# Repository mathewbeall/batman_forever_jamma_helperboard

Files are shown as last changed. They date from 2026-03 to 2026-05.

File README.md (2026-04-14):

# Batman Forever JAMMA Adapter

A JAMMA edge adapter board for the **Sega ST-V** arcade platform that enables the [Mitsurugi-w Batman Forever sound board repro](https://www.arcade-projects.com/threads/wait-list-batman-forever-sound-pcb-repro.27304/) to work in generic JAMMA cabinets.

This is a recreation and improvement of Derick2k's original design from the arcade-projects.com forum (thread post #191), which was abandoned ~2 years ago and never released.

> **Current production version: V1.2** — Fully tested and validated.
> **V1.3** — Design complete, not yet ordered or tested. See [V1.3 changes](#v13-changes-untested) below.

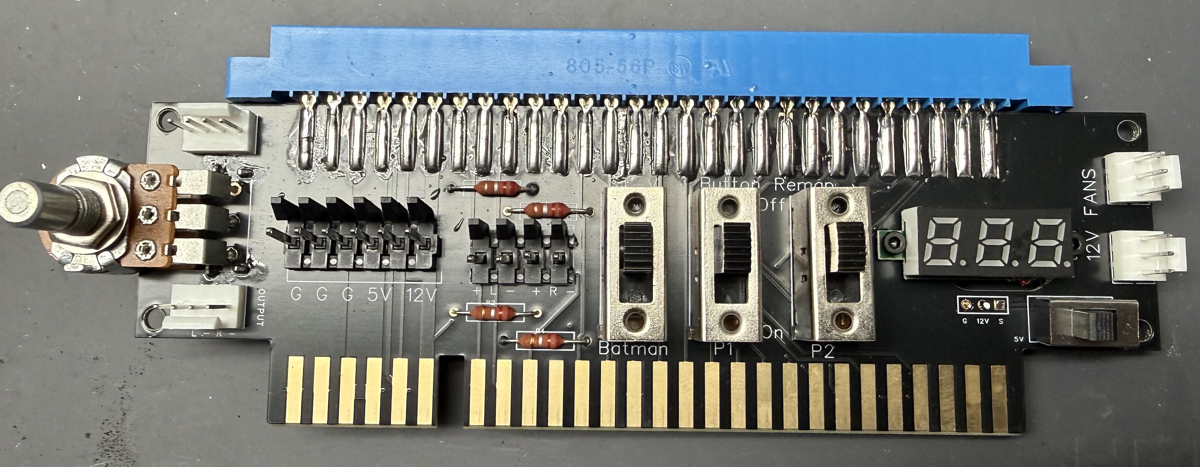
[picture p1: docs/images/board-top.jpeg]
Board top side

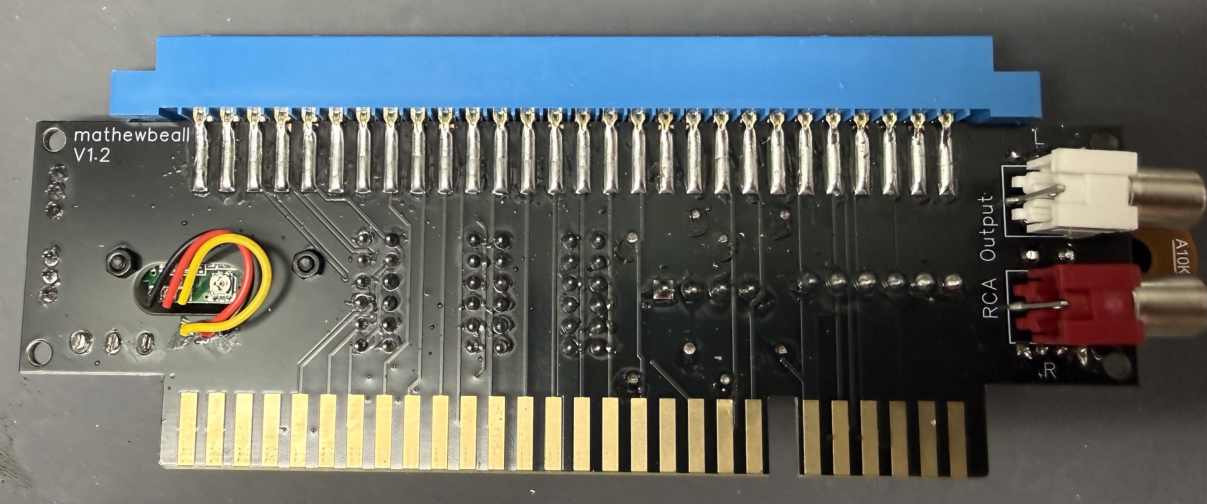
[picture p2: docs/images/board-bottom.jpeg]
Board bottom side

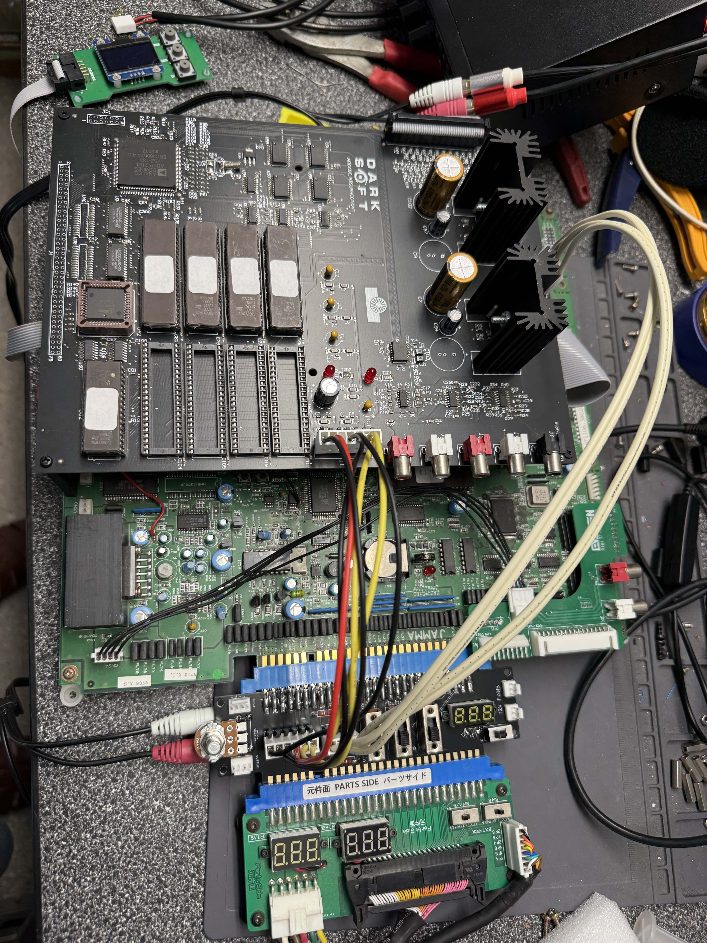
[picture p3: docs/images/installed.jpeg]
Installed with ST-V and sound board


---

## Features

- **Full JAMMA passthrough** — Video, controls, coins, test, service all pass through untouched
- **Power distribution** — Taps JAMMA 5V/12V/GND to power the sound board, fan headers, and voltmeter
- **Audio switching** — Single 4PDT slide switch selects ST-V native audio or Batman sound board output
- **Stereo-to-mono downmix** — Sound board's amplified stereo (BTL) output is summed to mono for the single JAMMA cabinet speaker
- **Button remapping** — Two 4PDT slide switches shift P1/P2 button mapping (Batman uses buttons 2/3/4 instead of 1/2/3)
- **Line-level audio** — Independent path with dual-gang volume pot, RCA jacks, and pin headers for external amplifiers
- **Voltage monitoring** — Slide switch selects 5V or 12V rail for a 0.28" voltmeter display module
- **Fan headers** — Two 3-pin fan connectors with 12V power
- **All through-hole** — Zero SMD components. Four resistors (audio ballast) are the only passives. Hand-solder friendly.

## Board Specifications

| Parameter | Value |
|---|---|
| Dimensions | 157mm x 50mm |
| Layers | 4 (Top, Inner1 GND, Inner2 Power, Bottom) |
| Copper Weight | 2oz all layers |
| PCB Color | Black solder mask, white silkscreen |
| Surface Finish | ENIG with gold fingers |
| Gold Finger Bevel | 45 degrees |
| Thickness | 1.6mm |
| Design Tool | EasyEDA Pro (JLCEDA Pro) |

---

## V1.2 — Production Version (Tested)

V1.2 is the current production version. Boards have been ordered, received, and fully validated.

**Quick Start (V1.2):**

1. **Order PCBs** — See the [Ordering Guide](docs/ordering-guide.md) for JLCPCB settings
2. **Order components** — See the [Bill of Materials](v1.2/bom.md) (~$32 per board in components)
3. **Build cables** — See the [Cable Build Guide](docs/cable-builds.md) for power and speaker cables
4. **Assemble** — See the [Assembly Guide](v1.2/assembly-guide.md) for soldering and setup instructions
5. **Install** — Set switches, plug into your cabinet, and play

**V1.2 Files:**

| File | Description |
|---|---|
| [v1.2/Batman_Forever_JAMMA_Adapter_V1.2.eprj](v1.2/Batman_Forever_JAMMA_Adapter_V1.2.eprj) | EasyEDA Pro project file |
| [v1.2/Gerber_PCB2_2026-03-20.zip](v1.2/Gerber_PCB2_2026-03-20.zip) | Production Gerbers for JLCPCB (tested) |
| [v1.2/assembly-guide.md](v1.2/assembly-guide.md) | Assembly guide |
| [v1.2/bom.md](v1.2/bom.md) | Bill of materials with full pricing |

**V1.2 switch note:** SW1/SW2/SW4 use the SS42H11-G9 4PDT slide switch (AliExpress). Before soldering, snip all 4 mounting lugs flush on each switch.

---

## V1.3 Changes (Untested)

> **V1.3 has not been ordered or tested.** The design is complete but unvalidated. Use V1.2 for production builds.

V1.3 replaces the three 4PDT slide switches (SW1/SW2/SW4) with the **Alps Alpine SSSU042100**, available from Mouser Electronics. The motivation is reliable domestic sourcing — the SS42H11-G9 used in V1.2 is only available from AliExpress with unpredictable lead times.

**What changed:**

| | V1.2 | V1.3 |
|--|---|---|
| Switch part | SS42H11-G9 (AliExpress) | SSSU042100 (Mouser 688-SSSU042100) |
| Row spacing | 4.0mm | 2.5mm |
| Pad drill | 1.1mm | 0.7mm |
| Mounting | 4 metal lugs to snip before soldering | Metal snap-in clips seat into 2 NPTH slots (1.5mm × 1.5mm) in the PCB — no prep required |
| Schematic | unchanged | unchanged |
| Electrical behavior | baseline | identical |

The SSSU042100 is electrically pin-compatible with the SS42H11-G9 — same 4PDT function, same 12-pin layout, same 3mm pitch. No schematic changes. The only differences are physical: smaller pin diameter (0.7mm vs 1.1mm), tighter row spacing (2.5mm vs 4.0mm), and a snap-in mounting mechanism that eliminates the lug-snipping step required on V1.2.

**V1.3 Files:**

| File | Description |
|---|---|
| [v1.3/Batman_Forever_JAMMA_Adapter_V1.3.eprj](v1.3/Batman_Forever_JAMMA_Adapter_V1.3.eprj) | EasyEDA Pro project file |
| [v1.3/Gerber_PCB2_2026-04-13.zip](v1.3/Gerber_PCB2_2026-04-13.zip) | Gerbers for JLCPCB (not yet ordered) |
| [v1.3/assembly-guide.md](v1.3/assembly-guide.md) | Assembly guide |
| [v1.3/bom.md](v1.3/bom.md) | Bill of materials with full pricing |

---

## Shared Documentation

| Document | Description |
|---|---|
| [Cable Build Guide](docs/cable-builds.md) | Power cable and speaker cable pinouts, crimping, safety |
| [Ordering Guide](docs/ordering-guide.md) | JLCPCB order settings and Gerber export instructions |

---

## Repository Structure

```
v1.2/                                    V1.2 — tested production version
  Batman_Forever_JAMMA_Adapter_V1.2.eprj   EasyEDA Pro project file
  Gerber_PCB2_2026-03-20.zip               Production Gerbers for JLCPCB
  assembly-guide.md                        Assembly guide
  bom.md                                   Bill of materials

v1.3/                                    V1.3 — design complete, NOT TESTED
  Batman_Forever_JAMMA_Adapter_V1.3.eprj   EasyEDA Pro project file
  Gerber_PCB2_2026-04-13.zip               Gerbers for JLCPCB (not yet ordered)
  assembly-guide.md                        Assembly guide
  bom.md                                   Bill of materials

docs/                                    Shared documentation
  cable-builds.md                          Power and speaker cable builds
  ordering-guide.md                        JLCPCB order settings
  images/                                  Board photos

soundboard_mounting_kit.scad/.stl        3D-printable sound board mounting parts
```

---

## 3D-Printable Sound Board Mounting Kit

The sound board mounts above the ST-V motherboard on standoffs, but the mounting holes don't align perfectly. The file `soundboard_mounting_kit.stl` contains a set of 3D-printable parts to bridge the gap:

| Part | Description |
|---|---|
| **Shim A** | 6mm offset adapter (single axis), M3 countersunk |
| **Shim B** | 6mm + 10mm offset adapter (two axes), M3 countersunk |
| **Spacer C** | Plain 3mm M3 spacer for aligned holes |
| **L-Bracket** | 25mm horizontal / 53mm vertical standoff for mounting points with no existing standoff |

All parts are 3mm thick (except the L-bracket pillar). M3 hardware throughout. Print in PETG or PLA, no supports needed. The OpenSCAD source (`soundboard_mounting_kit.scad`) is included if you need to adjust offsets.

---

## Stereo-to-Mono Downmixing

The Batman Forever sound board outputs amplified stereo via a bridged (BTL) amplifier — four wires: L+, L-, R+, R-. JAMMA only has a single speaker output (Speaker+, Speaker-).

SW4 (4PDT slide switch) handles this with direct BTL parallel summing: in Batman mode, L+ and R+ are tied together on Speaker+, and L- and R- are tied together on Speaker-. The speaker sees the sum of both channels across its terminals.

**V1.1** connects the channels directly, which works in practice but is not ideal — gain mismatch between channels can cause one to fight the other. **V1.2** adds four 0.22 ohm 1W series resistors (R1–R4) on the speaker lines between J4 and SW4 as current-sharing ballast, following the same approach recommended in TI's amplifier application notes. The resistors are small enough relative to the 8 ohm speaker load (2.75%) that audio loss is negligible.

In ST-V mode, SW4 simply passes the native JAMMA audio straight through to the cabinet.

The line-level audio path (RV1, RCA jacks, pin headers) is completely independent and always active regardless of SW4 position.

---

## Switch Settings

### SW4 — Audio Source
| Position | Mode | Description |
|---|---|---|
| Up (toward JAMMA edge) | **ST-V** | Native JAMMA audio passthrough |
| Down (toward tab) | **Batman** | Sound board audio to cabinet speakers |

### SW1/SW2 — Button Remap (P1/P2)
| Position | Mode | Description |
|---|---|---|
| Up (toward JAMMA edge) | **Off** | Normal 1:1 button passthrough |
| Down (toward tab) | **On** | Batman remap (shifts buttons +1) |

### SW3 — Voltmeter Select
| Position | Mode |
|---|---|
| Left | Displays 5V rail |
| Right | Displays 12V rail |

---

## Credits

- **Derick2k** — Original adapter board concept and PCB design (abandoned, never released)
- **Mitsurugi-w** — Batman Forever sound board reproduction
- **twistedsymphony** — Sound board connector pinouts from the original manual
- **Matt (mathewbeall)** — PCB recreation, schematic, and layout in EasyEDA Pro
- **arcade-projects.com community** — Testing, feedback, and support

## Forum Thread

[Interest List — Helper Board for Mitsu's Repro Batman Forever Sound/Amp Board](https://www.arcade-projects.com/threads/interest-list-helper-board-for-mitsus-repro-batman-forever-sound-amp-board.36822/)

## License

This project is licensed under the [CERN Open Hardware Licence Version 2 — Strongly Reciprocal (CERN-OHL-S-2.0)](LICENSE).

You are free to use, modify, and distribute this design. If you distribute modified versions, they must also be shared under the same licence.

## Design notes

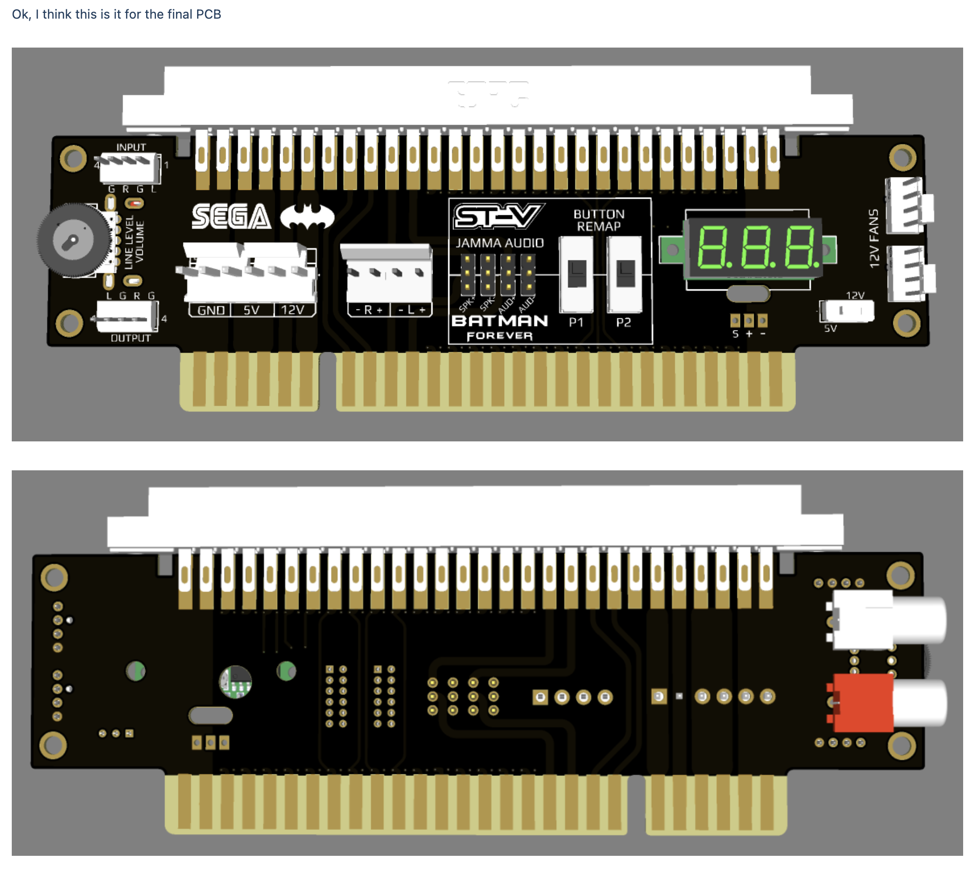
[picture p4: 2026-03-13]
final design.png

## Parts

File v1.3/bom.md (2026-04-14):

# Batman Forever JAMMA Adapter — Bill of Materials (V1.3)
**Last Updated: 2026-04-13**
**V1.3 change: SW1/SW2/SW4 switched from SS42H11-G9 (AliExpress) to Alps SSSU042100 (Mouser)**
**All prices verified against vendor listings**

---

## Per-Board Component Cost Summary

| Category | Subtotal |
|---|---|
| DigiKey — PCB-mount components | $4.95 |
| DigiKey — Cable parts | $6.15 |
| Mouser — Switches | $7.08 |
| Amazon — Voltmeter, IDE cable, SW3 | $4.90 |
| Adafruit — Pot | $2.75 |
| Memotronics — JAMMA connector | $2.69 |
| Wire (estimated per board) | $3.50 |
| **Components subtotal** | **$32.02** |
| Shipping estimate (10%) | $3.20 |
| **Total per board (components + shipping)** | **$35.22** |
| PCB cost (TBD — V1.3 not yet ordered) | TBD |
| **Grand total per assembled unit** | **TBD** |

---

## DigiKey — PCB-Mount Components

| Ref | Qty | Description | Mfr Part # | DigiKey Part # | Link | Price | Ext |
|-----|-----|---|---|---|---|---|-----|
| J3 | 1 | Molex KK 396 header, 6-pos, vertical, 3.96mm (power) | 0026481065 | WM50008-06-ND | [DigiKey](https://www.digikey.com/en/products/detail/molex/0026481065/26763) | $1.02 | $1.02 |
| J4 | 1 | Molex KK 396 header, 4-pos, vertical, 3.96mm (speaker) | 0026481045 | WM50008-04-ND | [DigiKey](https://www.digikey.com/en/products/detail/molex/0026481045/26759) | $0.79 | $0.79 |
| J7 | 1 | Kycon RCA jack, right-angle, 2-pin, RED (Left audio) | KLPX-0848A-2-R | 2092-KLPX-0848A-2-R-ND | [DigiKey](https://www.digikey.com/en/products/detail/kycon-inc/KLPX-0848A-2-R/9990119) | $0.83 | $0.83 |
| J8 | 1 | Kycon RCA jack, right-angle, 2-pin, WHITE (Right audio) | KLPX-0848A-2-W | 2092-KLPX-0848A-2-W-ND | [DigiKey](https://www.digikey.com/en/products/detail/kycon-inc/KLPX-0848A-2-W/9990120) | $0.83 | $0.83 |
| J9 | 1 | Molex KK 254, 4-pos, vertical, shrouded (line in) | 22-23-2041 | WM4202-ND | [DigiKey](https://www.digikey.com/en/products/detail/molex/0022232041/26671) | $0.26 | $0.26 |
| J10 | 1 | Molex KK 254, 4-pos, vertical, shrouded (line out) | 22-23-2041 | WM4202-ND | [DigiKey](https://www.digikey.com/en/products/detail/molex/0022232041/26671) | $0.26 | $0.26 |
| J14 | 1 | Molex KK 254, 3-pos, vertical, shrouded (fan) | 22-23-2031 | WM4201-ND | [DigiKey](https://www.digikey.com/en/products/detail/molex/0022232031/26669) | $0.22 | $0.22 |
| J15 | 1 | Molex KK 254, 3-pos, vertical, shrouded (fan) | 22-23-2031 | WM4201-ND | [DigiKey](https://www.digikey.com/en/products/detail/molex/0022232031/26669) | $0.22 | $0.22 |
| R1-R4 | 4 | 0.22 ohm 1W 5% axial resistor, metal film (audio ballast) | RR01JR22TB | A131610CT-ND | [DigiKey](https://www.digikey.com/en/products/detail/te-connectivity-passive-product/RR01JR22TB/2384744) | $0.13 | $0.52 |
| | | | | | | **Subtotal:** | **$4.95** |

**Note:** J3, J4, J9, J10, J14, J15 are dedicated Molex headers (not cut from breakaway strips). Voltmeter wires solder directly to pads — no header needed.

---

## DigiKey — Power Cable Parts (J3 → Sound Board J1)

| Qty | Description | Mfr Part # | DigiKey Part # | Link | Price | Ext |
|-----|---|---|---|---|---|-----|
| 1 | KK .156" 6-pin crimp housing (adapter J3 end) | 0009503061 | WM2104-ND | [DigiKey](https://www.digikey.com/en/products/detail/molex/0009503061/26461) | $0.26 | $0.26 |
| 1 | KK .156" 7-pin crimp housing (sound board J1 end) | 0009503071 | WM2105-ND | [DigiKey](https://www.digikey.com/en/products/detail/molex/0009503071/26463) | $0.36 | $0.36 |
| 15 | KK .156" crimp terminals, 18-24 AWG | 08-50-0106 | WM2300-ND | [DigiKey](https://www.digikey.com/en/products/detail/molex/0850-0106/26477) | $0.11 | $1.65 |
| | | | | | **Subtotal:** | **$2.27** |

**Power cable pinout:** See CLAUDE.md. J3 pins 1-2-3 = GND, pin 4 = +5V, pins 5-6 = +12V. Clean 1:1 cable to J1.

---

## DigiKey — Speaker Cable Parts (J4 → Sound Board J6)

| Qty | Description | Mfr Part # | DigiKey Part # | Link | Price | Ext |
|-----|---|---|---|---|---|-----|
| 1 | KK .156" 4-pin crimp housing (adapter J4 end) | 0009503041 | WM2102-ND | [DigiKey](https://www.digikey.com/en/products/detail/molex/0009503041/26457) | $0.17 | $0.17 |
| 1 | KK .156" 5-pin crimp housing (sound board J6 end) | 0009503051 | WM2103-ND | [DigiKey](https://www.digikey.com/en/products/detail/molex/0009503051/26459) | $0.22 | $0.22 |
| 9 | KK .156" crimp terminals, 18-24 AWG | 08-50-0106 | WM2300-ND | [DigiKey](https://www.digikey.com/en/products/detail/molex/0850-0106/26477) | $0.11 | $0.99 |
| | | | | | **Subtotal:** | **$1.38** |

**J6 Pinout:** 1=Speaker L+, 2=Speaker L-, 3=Speaker R+, 4=KEY (NC), 5=Speaker R-
**J4 on adapter:** 4-pin KK 396 receives pins 1,2,3,5 (skip pin 4 KEY)
**Speaker wire:** 18 AWG — uses same WM2300-ND crimp terminals as power cable.

---

## DigiKey — KK 254 Cable Parts (J9/J10 Line In/Out)

J9/J10 use Molex KK .100" (2.54mm) — different series from .156" power/speaker cables. J14/J15 fan cables not needed (fans come with hardwired connectors). This is the only cable using WM16517-ND (22-30 AWG) crimp terminals.

| Qty | Description | Mfr Part # | DigiKey Part # | Link | Price | Ext |
|-----|---|---|---|---|---|-----|
| 2 | KK 254, 4-pin crimp housing, no lock | 22-01-2041 | WM1577-ND | [DigiKey](https://www.digikey.com/en/products/detail/molex/0022012041/1090455) | $0.21 | $0.42 |
| 8 | KK 254 crimp terminals, 22-30 AWG | 0008500160 | WM16517-ND | [DigiKey](https://www.digikey.com/en/products/detail/molex/0008500160/3071500) | $0.26 | $2.08 |
| | | | | | **Subtotal:** | **$2.50** |

---

## DigiKey Total: $11.10

(PCB-mount: $4.95 + Power cable: $2.27 + Speaker cable: $1.38 + KK 254 cable: $2.50)

**⚠️ Buy extra crimp terminals** — budget 10-15% spares for crimp mistakes.

**⚠️ Crimp tool required** for Molex KK terminals — or carefully solder them.

---

## Mouser — Switches (V1.3)

| Ref | Qty | Description | Mfr Part # | Mouser Part # | Price | Ext | Notes |
|-----|-----|---|---|---|---|-----|---|
| SW1, SW2, SW4 | 3 | Alps Alpine 4PDT slide switch, 12-pin, vertical, 3mm pitch | SSSU042100 | 688-SSSU042100 | $2.36 | $7.08 | No lug prep needed — metal snap-in clips seat into PCB NPTH holes. Only 12 signal pins solder. |

**Note:** SSSU042100 uses metal snap-in retention clips that seat into dedicated PCB NPTH holes. Only the 12 signal pins solder. No lug snipping required.

---

## Amazon

| Ref | Qty | Description | Source | Per-Unit | Ext | Notes |
|-----|-----|---|---|---|-----|---|
| SW3 | 1 | SS-12D10 SPDT slide switch, 3-pin | [Amazon](https://www.amazon.com/dp/B07QB8RVKT) | $1.00 | $1.00 | Sold in 10-packs ($10). |
| — | 1 | 0.28" 3-digit voltmeter module, 3-wire | [Amazon](https://www.amazon.com/dp/B0BG31FBX5) | $1.40 | $1.40 | Sold in 10-packs ($14). Connects to J16. |
| — | 1 | 40-pin IDE ribbon cable (Darksoft multi → sound board) | [Amazon](https://www.amazon.com/dp/B07FZXK2D4) | $2.50 | $2.50 | Sold in 4-packs ($9.99). 30cm F/F IDC. |
| | | | | **Subtotal:** | **$4.90** | |

---

## Adafruit

| Ref | Qty | Description | Link | Price | Notes |
|-----|-----|---|---|---|---|
| RV1 | 1 | Alpha RV16A01F-41-15R1-A10K-30H4 dual-gang 10kΩ audio taper pot, right-angle | [Adafruit #5272](https://www.adafruit.com/product/5272) | $2.75 | Dry fit confirmed on test board |

---

## Memotronics

| Ref | Qty | Description | Link | Price | Notes |
|-----|-----|---|---|---|---|
| CN2 | 1 | 56-pin JAMMA female edge connector, PCB solder pin type | [Memotronics](https://memotronics.com/jamma-56-pin-arcade-card-edge-connector-socket-pcb-mount-3-96mm-0-156/) | $2.69 | **Must be solder pin, NOT solder eyelet.** Bifurcated gold-plated contacts. |

---

## Wire

| Qty | Description | Source | Per-Board | Notes |
|-----|---|---|---|---|
| ~3 ft | 18-20 AWG stranded (red, black, yellow) — power cable | [Amazon](https://www.amazon.com/) | ~$1.75 | From 25ft spool set ($27.50/set) |
| ~3 ft | 18-20 AWG stranded (4 colors) — speaker cable | [Amazon](https://www.amazon.com/) | ~$1.75 | From 25ft spool set ($27.50/set) |
| | | | **Subtotal: ~$3.50** | |

---

## Per-Board Cost Breakdown

| Category | Cost |
|---|---|
| DigiKey — PCB-mount headers/jacks/resistors | $4.95 |
| DigiKey — Cable housings & terminals | $6.15 |
| Mouser — Switches (SW1/SW2/SW4) | $7.08 |
| Amazon — Voltmeter, IDE cable, SW3 | $4.90 |
| Adafruit — RV1 pot | $2.75 |
| Memotronics — CN2 JAMMA connector | $2.69 |
| Wire (estimated per board) | $3.50 |
| **Components subtotal** | **$32.02** |
| Shipping estimate (10%) | $3.20 |
| **Total per board (components + shipping)** | **$35.22** |
| PCB cost (TBD — V1.3 not yet ordered) | TBD |
| **Grand total per assembled unit** | **TBD** |

---

## Notes

1. **V1.3 switch change:** SW1/SW2/SW4 are now Alps SSSU042100 (Mouser 688-SSSU042100) instead of SS42H11-G9 (AliExpress). Same 3mm pitch, same 12-pin layout, same electrical behavior. No schematic changes. No lug prep required. Footprint adds 2 NPTH holes (ø1.5mm) for the metal snap-in retention clips.
2. **V1.2 adds 4 resistors** (R1-R4, 0.22 ohm ballast for BTL audio summing). No capacitors. All other routing is direct wire.
3. **All through-hole** — no SMD. Hand solder everything.
4. **RCA jacks (Kycon KLPX-0848A-2) mount on the BOTTOM layer.** True 2-pin design (1 GND + 1 signal). Flush-cut J7/J8 pins on top for RV1 clearance.
5. **CN2 (JAMMA female connector)** is soldered onto the top edge gold fingers — mechanical part, not a PCB component.
6. **SW4 replaces JP1-JP4** — single switch for ST-V/Batman audio mode selection.
7. **RV1 taper is audio (A10K)**, not linear (B10K) — correct for volume control.
8. **40-pin IDE cable** connects Darksoft multi edition to the sound board.
9. **Standoffs** — TBD, not yet sourced.
10. **Prices verified 2026-04-13.** Per-unit prices calculated from bulk pack costs where applicable.

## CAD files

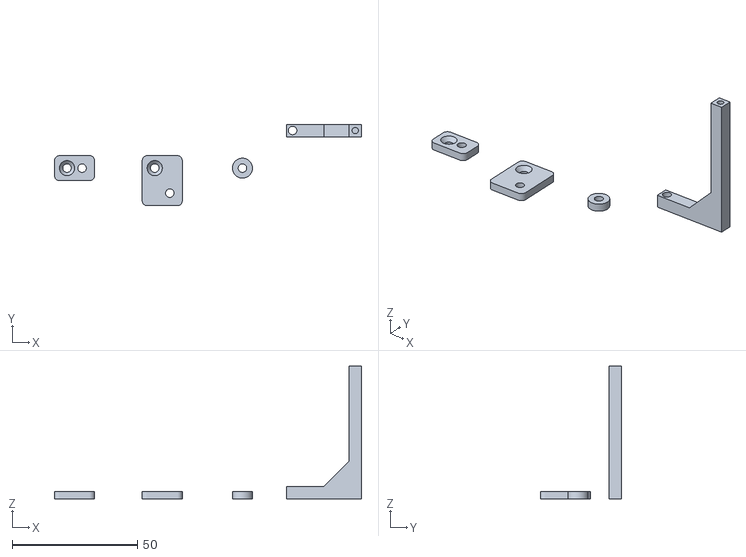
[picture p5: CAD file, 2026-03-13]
soundboard_mounting_kit.stl
122.5 x 32.5 x 53.0

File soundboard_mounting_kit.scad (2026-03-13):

// Batman Forever sound board mounting kit - all parts on one plate
//
// Shim A:  6mm X offset, countersunk standoff hole
// Shim B:  6mm X / -10mm Y offset, countersunk standoff hole
// Shim C:  Plain spacer, no offset, no countersink
// Bracket: L-bracket standoff, 25mm horizontal, 53mm vertical

$fn = 60;

// === Shared parameters ===
m3_clearance  = 3.4;
m3_head_dia   = 6.2;
m3_head_depth = 1.8;

// === Shim parameters ===
shim_thickness = 3;
corner_radius  = 2;
pad            = 5;

// === Bracket parameters ===
wall          = 5;
h_offset      = 25;
v_height      = 53;
m3_pilot      = 2.5;
pilot_depth   = 10;

// === Layout ===
shim_spacing = 35;

// Shim A
translate([0, 0, 0])
    shim([6, 0]);

// Shim B
translate([shim_spacing, 0, 0])
    shim([6, -10]);

// Shim C (plain spacer)
translate([shim_spacing * 2, 0, 0])
    spacer();

// L-bracket - placed to the right with clearance
translate([shim_spacing * 2 + 20, 15, 0])
    bracket();


// === Shim modules ===

module shim(offset) {
    min_x = min(0, offset[0]) - pad;
    max_x = max(0, offset[0]) + pad;
    min_y = min(0, offset[1]) - pad;
    max_y = max(0, offset[1]) + pad;

    width  = max_x - min_x;
    height = max_y - min_y;

    cx = (min_x + max_x) / 2;
    cy = (min_y + max_y) / 2;

    difference() {
        translate([cx, cy, shim_thickness/2])
            rounded_box(width, height, shim_thickness, corner_radius);
        countersunk_hole(0, 0);
        plain_hole(offset[0], offset[1]);
    }
}

module spacer() {
    outer_dia = 8;
    difference() {
        cylinder(h = shim_thickness, d = outer_dia);
        translate([0, 0, -0.1])
            cylinder(h = shim_thickness + 0.2, d = m3_clearance);
    }
}

// === Bracket module ===

module bracket() {
    difference() {
        union() {
            // Horizontal arm
            translate([-wall/2, -wall/2, 0])
                cube([h_offset + wall/2, wall, wall]);

            // Vertical pillar
            translate([h_offset - wall/2, -wall/2, 0])
                cube([wall, wall, v_height]);

            // Inside corner fill - vertical triangle, same width
            translate([0, -wall/2, 0])
                rotate([90, 0, 0])
                    translate([0, 0, -wall])
                        linear_extrude(wall)
                            polygon([
                                [h_offset - wall/2 - 10, wall],
                                [h_offset - wall/2, wall],
                                [h_offset - wall/2, wall + 10]
                            ]);
        }

        // Base through-hole
        translate([0, 0, -0.1])
            cylinder(h = wall + 0.2, d = m3_clearance);

        // Top pilot hole
        translate([h_offset, 0, v_height - pilot_depth])
            cylinder(h = pilot_depth + 0.1, d = m3_pilot);
    }
}

// === Shared hole modules ===

module plain_hole(x, y) {
    translate([x, y, -0.1])
        cylinder(h = shim_thickness + 0.2, d = m3_clearance);
}

module countersunk_hole(x, y) {
    translate([x, y, -0.1]) {
        cylinder(h = shim_thickness + 0.2, d = m3_clearance);
        translate([0, 0, shim_thickness - m3_head_depth + 0.1])
            cylinder(h = m3_head_depth + 0.1, d1 = m3_clearance, d2 = m3_head_dia);
    }
}

module rounded_box(w, h, t, r) {
    hull() {
        for (x = [-(w/2 - r), (w/2 - r)])
            for (y = [-(h/2 - r), (h/2 - r)])
                translate([x, y, 0])
                    cylinder(h = t, r = r, center = true);
    }
}

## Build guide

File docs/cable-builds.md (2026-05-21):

# Cable Build Guide

## Power Cable (Power Header → Sound Board J1)

6-pin on the adapter side, 7-pin on the sound board side (pin 5 is the key — leave empty).

| Adapter Pin | Signal | Wire Color | → | Sound Board J1 Pin | Signal |
|---|---|---|---|---|---|
| 1 | GND | Black | → | 3 | GND |
| 2 | GND | Black | → | 4 | GND |
| 3 | GND | Black | → | 7 | GND |
| 4 | +5V | Red | → | 6 | +5V |
| 5 | +12V | Yellow | → | 1 | +12V |
| 6 | +12V | Yellow | → | 2 | +12V |
| — | — | — | — | 5 (KEY) | Empty |

Silkscreen on the adapter reads "G G G 5V 12V" (left to right, pin 1 on the left when viewing from the front).

### Parts

| Qty | Description | DigiKey PN |
|-----|---|---|
| 1 | KK .156" 6-pin crimp housing (adapter end) | WM2104-ND |
| 1 | KK .156" 7-pin crimp housing (sound board end) | WM2105-ND |
| 12+ | KK .156" crimp terminal, **18-24 AWG** | WM2300-ND |

Use 18 AWG stranded wire. **Do NOT use WM1114-ND terminals — they are 22-30 AWG only and cannot crimp 18 AWG wire.**

---

## Speaker Cable (Speaker Header → Sound Board J6)

4-pin on the adapter side, 5-pin on the sound board side (pin 4 is the key — leave empty).

| Sound Board J6 Pin | Signal | → | Adapter Pin |
|---|---|---|---|
| 1 | Speaker L+ | → | 1 |
| 2 | Speaker L- | → | 2 |
| 3 | Speaker R+ | → | 3 |
| 4 | KEY (NC) | — | skip |
| 5 | Speaker R- | → | 4 |

Silkscreen on the adapter reads "+ L - + R -".

### Parts

| Qty | Description | DigiKey PN |
|-----|---|---|
| 1 | KK .156" 4-pin crimp housing (adapter end) | WM2102-ND |
| 1 | KK .156" 5-pin crimp housing (sound board end) | WM2103-ND |
| 9+ | KK .156" crimp terminal, **18-24 AWG** | WM2300-ND |

Use 18 AWG stranded wire. Same terminals as the power cable.

---

## Line-Level Audio Cables (INPUT / OUTPUT Headers)

These connect the sound board's RCA line-level outputs to the adapter's INPUT header, and the adapter's OUTPUT header to an external amplifier (via RCA jacks or direct).

### Sound Board RCA Jacks

Five RCA jacks on the right edge of the sound board, top to bottom:

| Position | Jack | Function |
|---|---|---|
| 1 (top) | J12 | Unamplified combined mono output (for external amp) |
| 2 | J13 | Line-level output — Left channel |
| 3 | J14 | Line-level output — Right channel |
| 4 | J10 | Mix-in input — Left channel |
| 5 (bottom) | J11 | Mix-in input — Right channel |

Source: Mitsurugi-w's resources thread, image `bat_rca2.jpg`.

Connect J13 (Left) and J14 (Right) to the adapter's INPUT header.

### Parts

| Qty | Description | DigiKey PN |
|-----|---|---|
| 2 | KK 254 4-pin crimp housing, no lock | WM1577-ND |
| 8+ | KK 254 crimp terminal, 22-30 AWG | WM16517-ND |

Use 22 AWG stranded wire.

---

## Safety

- **Always verify no shorts between +5V, +12V, and GND at both connector ends before powering on.**
- Double-check pin 5 (KEY) on the sound board housings is left empty.
- Budget 50% extra crimp terminals for mistakes.
- A proper Molex crimp tool is recommended. Crimping with pliers works but is less reliable.

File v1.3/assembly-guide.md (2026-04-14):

# Batman Forever JAMMA Adapter — Assembly Guide

**Board Version:** V1.3
**V1.3 change:** SW1/SW2/SW4 are Alps SSSU042100 (Mouser). No lug prep required — metal snap-in retention clips seat into dedicated PCB holes. Only the 12 signal pins solder.
**All components are through-hole. No SMD. Four resistors (R1-R4) are the only passives.**

---

## Tools Required

- Soldering iron (adjustable temp recommended — 350-370°C for ground plane pins)
- Solder (60/40 or 63/37 leaded recommended for through-hole)
- Flush cutters
- Needle-nose pliers
- Crimp tool for Molex KK terminals (or solder carefully)

---

## Before You Start

- Inspect the bare PCB for manufacturing defects, especially the gold finger edge and via fills.
- Gather all components and verify against the [Bill of Materials](bom.md).
- **No switch prep needed** — the SSSU042100 uses metal snap-in retention clips that seat into dedicated PCB holes. Just press the switch in until the clips snap through, then solder the 12 signal pins. Orientation does not matter — the switches are electrically symmetric.

---

## Soldering Order

The order matters — some components block access to others if installed first. Follow this sequence.

### Step 1: JAMMA Female Connector

Solder this first while the board is empty and you have plenty of room to work.

- The 56-pin JAMMA female edge connector solders onto the gold finger pads on the top edge.
- **Must be solder-pin type, NOT solder eyelet.**
- Align carefully before tacking a few pins, then solder all 56.

### Step 2: Volume Pot

Solder the Alpha RV16A01F dual-gang pot. The ground pins connect to heavy copper pours on multiple layers, so they will sink a lot of heat.

- Apply extra heat and dwell time on the ground pins — they take noticeably longer to flow.
- Verify the pot is seated flush to the board before soldering.
- **Flush-cut all pins on the bottom side** — the RCA jacks mount directly behind this area and need clearance.

### Step 3: RCA Jacks (Bottom Side)

The Kycon KLPX-0848A-2 RCA jacks mount on the **bottom** of the board (solder from the top). There is not a lot of room to maneuver around the volume pot, which is why it gets soldered and trimmed first. Silkscreen on the bottom reads "RCA Output" with "L" and "R" labels.

- Red jack = Left audio (labeled "L" on bottom silk)
- White jack = Right audio (labeled "R" on bottom silk)
- Apply extra heat — ground pins connect to copper pours.
- Verify jacks are seated flat against the bottom of the board before soldering.

### Step 4: Line In/Out Headers

Solder the two Molex KK 254 4-pos shrouded headers. Silkscreen labels read "INPUT" and "OUTPUT" with pin labels "- R - L" and "L - R -".

- INPUT header = line level input from sound board
- OUTPUT header = line level output to external amp
- Key tab orientation should match the silkscreen.

### Step 5: Power Header

Solder the Molex KK 396 6-pos header. Silkscreen pin labels read "G G G 5V 12V".

- This is the power connector to the sound board — carries GND, +5V, and +12V.
- Ensure fully seated before soldering.

### Step 6: Speaker Header

Solder the Molex KK 396 4-pos header. Silkscreen pin labels read "+ L - + R -".

- Speaker input from the sound board.

### Step 7: Audio Ballast Resistors

Solder the four 0.22 ohm 1W axial resistors (TE RR01JR22TB) above and below the speaker header.

- These are current-sharing ballast resistors for the BTL parallel mono summing circuit.
- Resistor body is smaller than the footprint — bend leads to match 12.8mm pad spacing.
- Orientation does not matter (resistors are not polarized).

### Step 8: Audio Source Switch

Solder the Alps SSSU042100 4PDT slide switch. Silkscreen labels read "ST-V" and "Batman".

- Press the switch into the PCB — the metal snap-in clips pass through the dedicated NPTH holes and lock. No lug snipping required.
- Orientation does not matter — switches are electrically symmetric.
- ST-V (up, toward keyed JAMMA edge) / Batman (down, away from keyed JAMMA edge).

### Step 9: Button Remap Switches (P1/P2)

Solder both Alps SSSU042100 4PDT slide switches. Silkscreen reads "Button Remap" with "P1" and "P2" labels, and "Off" / "On" positions.

- P1 = Player 1 remap
- P2 = Player 2 remap
- Orientation does not matter.
- Off (up, toward keyed JAMMA edge) / On (down, away from keyed JAMMA edge).

### Step 10: Voltmeter Select Switch

Solder the SS-12D10 SPDT slide switch. Silkscreen reads "5V" next to it.

- Selects between 5V and 12V rail display on the voltmeter.

### Step 11: 12V Fan Headers

Solder the two Molex KK 254 3-pos shrouded headers. Silkscreen reads "12V FANS".

- Key tab should face the outside edge of the board (toward the board edge, not inward).
- Pin 1 = GND, Pin 2 = +12V, Pin 3 = NC.
- Standard 3-pin PC fan connectors plug in with the key on the outside.

### Step 12: Voltmeter Module

- **Flush-cut the long pins on the back of the voltmeter module** before mounting — they will interfere with the board otherwise.
- Mount the module in the cutout area on the front of the board using M3 hardware (bolt and nut).
- Solder the module's 3 wires directly into the header holes from the back of the board. No pin header needed.
- Silkscreen reads "G 12V S" — match the wires from the voltmeter module:
  - G = black wire (GND)
  - 12V = red wire (power)
  - S = yellow wire (signal/measurement input)
- There is a small adjustment screw on the back of the module, reachable through the cutout, for calibrating the readout. Use a known-good multimeter to verify the voltage and adjust as needed.

---

## Post-Soldering Checks

Before powering on:

1. **Visual inspection** — Check all solder joints for bridges, cold joints, and missed pins.
2. **Continuity check** — Verify no shorts between +5V, +12V, and GND at the power header.
3. **Connector check** — Verify all shrouded headers have key tabs oriented correctly.

---

## Cable Builds

See the [Cable Build Guide](../docs/cable-builds.md) for power cable and speaker cable pinouts, wire gauges, and crimping instructions.

---

## Switch Settings

| Switch | Up (toward keyed JAMMA edge) | Down (away from keyed JAMMA edge) |
|---|---|---|
| Audio (ST-V / Batman) | ST-V (passthrough) | Batman (sound board) |
| P1 Button Remap | Off (normal buttons) | On (Batman remap) |
| P2 Button Remap | Off (normal buttons) | On (Batman remap) |

| Voltmeter Switch | Left | Right |
|---|---|---|
| Rail Select | 5V | 12V |

**All switches should be in ST-V / Off position for initial power-on testing.**

---

## Initial Power-On Test

1. Set audio switch to ST-V, both button remap switches to Off.
2. Insert board into JAMMA harness — do NOT connect the sound board yet.
3. Power on — verify video and native audio pass through to the cabinet.
4. Check voltmeter reads correct voltage for the selected rail.
5. If passthrough works, power off, connect sound board cables, and test Batman mode.

---

## Mono Downmix Notes (Batman Mode)

When the audio switch is set to Batman, the adapter sums the sound board's stereo BTL amplifier outputs to mono for the JAMMA cabinet speaker. This is the most demanding operating mode for the sound board's amplifiers.

**Why ballast resistors R1-R4 are needed:**

When two BTL amplifier channels are paralleled for mono summing, small gain differences between the left and right channels cause cross-channel current — one amp tries to source current while the other sinks it. This wastes power as heat rather than driving the speaker. The 0.22 ohm ballast resistors limit this cross-channel current path.

**Symptoms observed on V1.1 (no ballast resistors):**

- **Cold-start oscillation** — Low-frequency feedback/motorboating when the sound board's heatsinks are cold. Clears after the amp warms up, as thermal drift brings channel gains closer together. Toggling the audio switch to ST-V and back also clears it.
- **Elevated heatsink temperature** — In normal speaker mode (driving speakers directly), the sound board heatsinks are barely warm. In downmix mode without resistors, they get noticeably hot due to cross-channel current dissipation.
- **More stable power rails** — The 12V and 5V rails fluctuate less in downmix mode compared to normal speaker mode, because the cross-channel current draw is more constant (amps fighting each other) vs. the dynamic current draw of actually driving speakers with audio signal.

All three symptoms point to the same root cause: uncontrolled cross-channel current between paralleled BTL outputs. Ballast resistors address this.

**Verification after build:** Compare sound board heatsink temperature and 12V rail stability between ST-V mode and Batman mode. Heatsinks should run cooler and rails should be more stable than V1.1 in downmix mode.

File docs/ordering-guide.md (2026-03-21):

# PCB Ordering Guide — JLCPCB

## Gerber Files

Use `Gerber_PCB2_2026-03-20.zip` from this repo. Upload directly to [JLCPCB](https://jlcpcb.com).

## Order Settings

| Setting | Value |
|---|---|
| Quantity | 20 (or as needed) |
| Layers | 4 |
| Thickness | 1.6mm |
| PCB Color | Black |
| Surface Finish | ENIG |
| Gold Thickness | 1U" |
| Gold Fingers | Yes |
| Gold Finger Bevel | 45° |
| Outer Copper Weight | 2oz |
| Inner Copper Weight | 2oz |
| Via Covering | Plugged |
| Board Outline Tolerance | ±0.2mm |
| Electrical Test | Flying Probe Fully Test |
| Mark on PCB | Remove Mark |

## Notes

- Gold fingers and ENIG are required — the JAMMA edge connector solders directly to the gold finger pads.
- 45° bevel is needed for smooth insertion into JAMMA harnesses.
- 2oz copper on all layers provides better current handling for the power traces.
- "Remove Mark" keeps the JLCPCB order number off the board.

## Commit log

2026-03-13 Initial release — Batman Forever JAMMA Adapter V1.1
    Complete open-source hardware release of the ST-V Batman Forever
    JAMMA adapter board. Includes EasyEDA Pro project file, full
    documentation (assembly guide, cable builds, BOM, ordering guide),
    Derick2k's original reference files, and 3D-printable test jig.
    Production boards ordered from JLCPCB (20x, black, ENIG, 2oz, 45° bevel).
    [sw4_test_jig.scad, sw4_test_jig.stl]
2026-03-13 Update BOM with verified prices and links
    - All DigiKey, Amazon, AliExpress, Adafruit, and Memotronics prices
    verified against actual vendor listings (2026-03-12)
    - Fixed RV1: Adafruit #5272 (A10K audio taper), was #5274 (B10K linear)
    - Fixed KK 254 housing PN: 22-01-2041, was 22-01-2047
    - Added per-board cost summary with 10% shipping estimate
    - Added 40-pin IDE cable and wire costs
    - Grand total per assembled unit: ~$52.50 (including PCB)
    - Added CLAUDE.md to .gitignore
2026-03-13 Add switch orientation test guide for SS42H11-G9
    Step-by-step continuity test to determine correct orientation
    before soldering SW1, SW2, and SW4. No pin 1 marking on the
    switch — this test identifies Position 1 vs Position 2 so the
    silkscreen labels match the slider direction.
2026-03-13 Add 3D-printable sound board mounting kit
    Offset shims and L-bracket for mounting the Batman Forever sound board
    above the ST-V motherboard where standoff holes don't align.
    [soundboard_mounting_kit.scad, soundboard_mounting_kit.stl]
2026-03-13 Remove switch orientation test guide — SS42H11-G9 is electrically symmetric
    The 4PDT slide switch can be soldered in either orientation. A 180° rotation
    swaps Throw 1/Throw 2 AND reverses slider direction, which cancel out.
    Silkscreen labels are correct regardless of switch orientation.
2026-03-13 Add stereo-to-mono downmixing explanation to README
    Documents the Taito L+/R- method used by SW4 to combine the sound
    board's bridged amplifier stereo output into JAMMA's single speaker.
2026-03-13 Fix misleading 'Taito L+/R-' audio terminology
    The so-called 'Taito L+/R- method' incorrectly implies only Left positive
    and Right negative are used. The actual circuit parallels both full BTL
    channels: L+ and R+ to Speaker+, L- and R- to Speaker-. Updated README
    and spec to use accurate terminology.
2026-03-13 Add V1.2 spec for audio summing resistors
    V1.1 directly parallels BTL amplifier outputs for stereo-to-mono,
    which works but risks gain mismatch issues. V1.2 adds 4x 0.22 ohm 1W
    series resistors (R1-R4) on the speaker lines between J4 and SW4 as
    current-sharing ballast. Includes full schematic/layout change spec.
2026-03-21 V1.2 updates: assembly guide, BOM, punch list
    - Assembly guide rewritten from V1.1 build experience: CN2 first,
    RCA jack lug snipping, resistor placement, silkscreen labels
    instead of J designators, voltmeter wired directly (no header)
    - BOM: added R1-R4 (TE RR01JR22TB 0.22 ohm 1W), switched J9/J10
    crimp terminals to WM16517-ND, updated all totals with full
    project cost amortization ($67.30/unit break-even)
    - Punch list: all 24 items closed, J14/J15 fan header key fix added
    and completed
    - README: updated status to V1.2, passives note corrected
2026-03-21 Clean up repo for public use: V1.2 design, Gerbers, docs
    - Add V1.2 .eprj and Gerber files (Gerber_PCB2_2026-03-20.zip)
    - Recreate cable-builds.md and ordering-guide.md
    - Move reference files to Jamma_Adapter/, design image to root
    - Remove CHANGELOG, LICENSE, obsolete extras
    - Update .gitignore to exclude working files, backups, snapshots
    - Add specs/context-file.md
    [sw4_test_jig.scad, sw4_test_jig.stl]
2026-03-21 Replace J designators with silkscreen labels in BOM
    BOM now references what builders see on the board (Power header,
    Speaker header, INPUT, OUTPUT, 12V FANS, etc.) instead of internal
    schematic J designators that aren't on the silkscreen.
2026-03-21 Remove voltmeter pin header from BOM — wires solder directly to pads
2026-03-21 Add voltmeter mounting notes: flush-cut pins, M3 hardware
2026-03-21 Add sound board RCA jack reference to cable build guide
2026-03-21 Update BOM: speaker cable uses 18AWG wire with WM2300-ND crimps
    Speaker cable now uses same 18AWG wire and 08-50-0106/WM2300-ND crimp
    terminals as power cable. WM16517-ND (22-30AWG) only used for line
    level cables (J9/J10). Updated per-board costs and totals.
2026-03-21 Update break-even: $681.27 PCB cost / 24 sellable V1.2 boards
    V1.0 (5 test, not charged) + V1.1 (20 @ $345.99) + V1.2 (25 @ $335.28).
    Only V1.2 boards are sellable (V1.1 has BTL oscillation issue).
    Break-even per unit: $64.86.
2026-03-21 Add mono downmix troubleshooting notes to assembly guide
    Documents V1.1 observations: cold-start oscillation, elevated heatsink
    temps, and power rail behavior when BTL outputs are paralleled without
    ballast resistors. Explains why V1.2 added R1-R4.
2026-04-04 Clean up repo for public release
    - Add CERN-OHL-S-2.0 LICENSE file
    - Remove obsolete V1.0/V1.1 design files, specs, and punch list
    - Sync public BOM with latest pricing ($59.36/unit)
    - Fix speaker cable terminals in docs (WM2300-ND, not WM16517-ND)
    - Update README: fix repo structure, remove broken links, update status
    - Update .gitignore to exclude old versions and internal docs
2026-04-04 Fix assembly guide: volume pot pin flush-cut is on bottom side, not top
2026-04-04 Remove RCA jack lug snipping note — not needed for V1.2 footprint
2026-04-04 Update forum thread link to dedicated helper board interest list
2026-04-04 Add board photos to README
2026-04-14 Add V1.3 design: replace SS42H11-G9 with Alps SSSU042100
    SW1/SW2/SW4 footprint updated for Alps SSSU042100 (Mouser 688-SSSU042100):
    - Row spacing 4.0mm → 2.5mm
    - Drill 1.1mm → 0.7mm
    - Pad OD 1.8mm → 1.4mm
    - Pin 1 square pad + body silkscreen outline
    - Version silkscreen updated V1.2 → V1.3
    SSSU042100 is US-stocked at Mouser, same 3mm pin pitch and 12-pin
    layout as SS42H11-G9. Plastic snap-in legs (no lug snipping needed).
    Pin numbering identical — no schematic changes.
2026-04-14 Fix V1.3 switch footprint silkscreen to correct body dimensions
    Corrected body outline from 22.5mm → 21.5mm width (actual SSSU042100
    body per datasheet). Depth was already correct at 7.0mm.
    Also confirmed: SSSU042100 frame legs are spring clips that grip PCB
    edges from outside — no NPTH holes needed. The footprint is 12×ø0.7mm
    signal holes only, per the Alps mounting hole diagram.
2026-04-14 V1.3: Add NPTH holes for SSSU042100 frame leg clips; fix docs
    - Add 2 NPTH holes (ø1.5mm) to sw_4pdt_slide_12pin footprint at
    ±11.25mm from center (A=22.5mm frame leg spacing per Alps datasheet)
    - Footprint now has 14 PCB holes: 12 signal (ø0.7mm) + 2 frame leg NPTH
    - Fix assembly guide and BOM: clips are metal, not plastic
2026-04-14 V1.3: Correct NPTH hole positions to 21.5mm apart
    Frame leg clips are at the body edge (±10.75mm from center),
    not at the full 22.5mm tip span. Holes now align with the
    silkscreen body outline corners.
2026-04-14 V1.3: Fix NPTH pad format — type_code 0→12, add pin IDs 13/14
    EasyEDA Pro requires type_code=12 for all through-hole pads.
    Using 0 caused the PCB view to hang on load.
2026-04-14 V1.3: NPTH holes → 1.5mm square slots; remove pin-1 notch
    - NPTH holes changed from round ø1.5mm to RECT 1.5mm×1.5mm to match
    the 4-R0.2 rounded-rectangle clip profile from Alps datasheet
    - Remove pin-1 notch from silkscreen — switch is electrically symmetric,
    orientation irrelevant, and notch caused visual centering confusion
2026-04-14 Reorganize repo into v1.2/ and v1.3/ directories
    - v1.2/: .eprj, Gerbers, assembly guide, BOM (tested production version)
    - v1.3/: .eprj, assembly guide, BOM (design complete, NOT TESTED)
    - docs/: shared cable-builds and ordering-guide remain at root of docs/
    - Remove redundant docs/bom.md (superseded by version-specific bom.md files)
    - Update all internal links to reflect new paths
    - README: restructured with clear V1.2/V1.3 sections, V1.3 untested warning,
    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
2026-04-14 Add V1.3 Gerbers; update README
2026-05-21 docs: document all 5 sound board RCA jacks with physical layout
    Add top-to-bottom ordering and J12 (combined mono) identifier sourced
    from Mitsurugi-w's bat_rca2.jpg in the resources thread.
2026-05-31 docs: update board photos with new front and back images
